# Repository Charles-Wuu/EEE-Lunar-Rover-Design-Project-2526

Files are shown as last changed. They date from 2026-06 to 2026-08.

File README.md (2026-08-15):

# EEE Lunar Rover Project 2026 - Group 25

**Good news! Our work was selected by the Department of EEE for the Best First
Year Project 2026 prize, recognising the dedication and hard work of the whole
team. Congratulations to everyone involved.**

This repository contains the organised software, firmware, CAD, presentation,
and final report materials for the Group 25 ELEC40006 summer rover project.

The rover is a WiFi-controlled lunar surface rover designed to navigate towards
artificial rocks, read their magnetic, infrared, ultrasound, and RF signals, and
classify the rock type from those sensor readings.

Artificial Lunar Surface

## Project photos

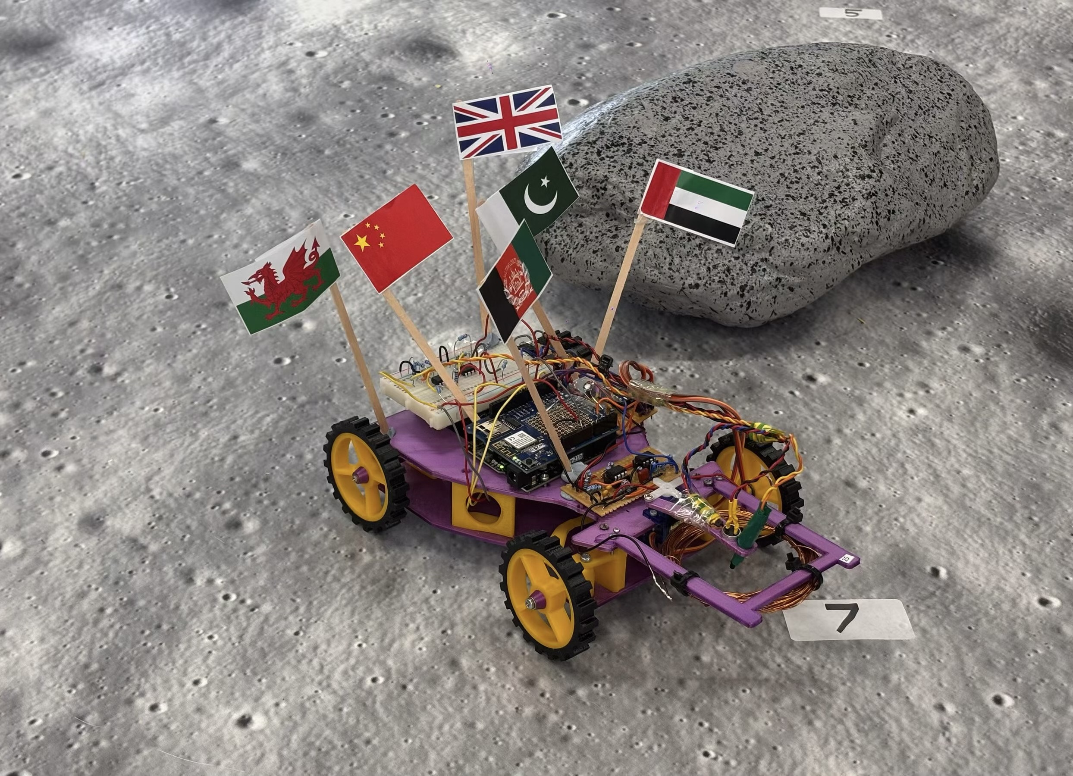
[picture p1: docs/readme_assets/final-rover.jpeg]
Final rover


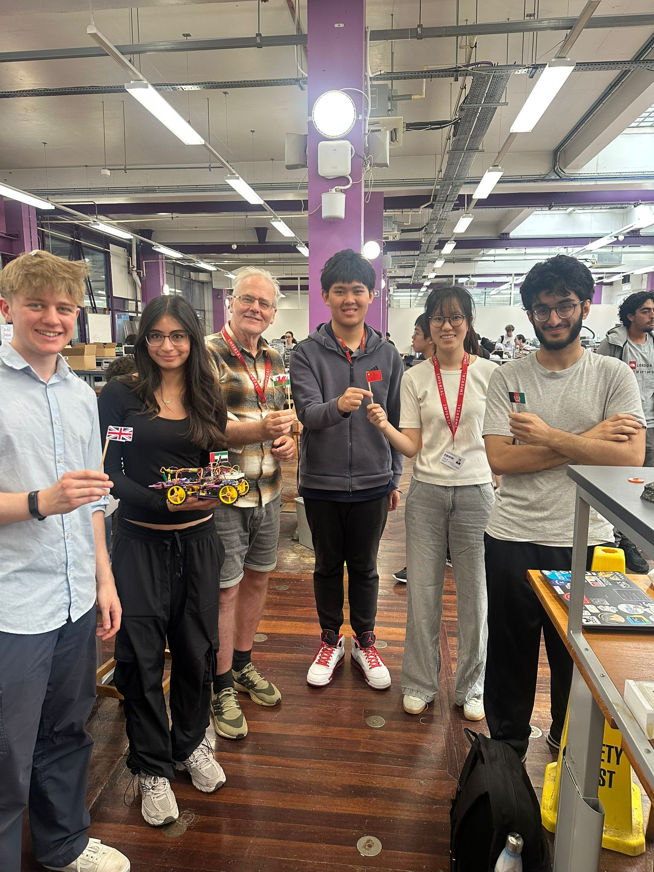
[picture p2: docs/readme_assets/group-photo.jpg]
Group photo


## Repository layout

| Path | Contents |
| --- | --- |
| [`firmware/arduino/final/`](firmware/arduino/final/) | Final combined rover control and detection Arduino sketch. |
| [`firmware/arduino/tests/`](firmware/arduino/tests/) | Earlier tested sketches for control, detection, and RF experiments. |
| [`software/web/`](software/web/) | Flask bridge server and browser interfaces for control and detection. |
| [`mechanical/cad/`](mechanical/cad/) | Full rover STL assembly and individual 3D-printable STL parts. |
| [`docs/report/`](docs/report/) | Final project report PDF. |
| [`docs/presentation/`](docs/presentation/) | Interim presentation PDF. |

## System summary

- Primary controller: Adafruit Metro M0 Express with WINC1500 WiFi shield.
- Rover structure: rear-wheel drive with front-wheel steering.
- Sensor head: combined magnetic, IR, ultrasound, and RF sensing mount.
- Front end: browser pages for mode selection, manual control, and detection.
- Server bridge: Flask app that proxies commands/data between a laptop and the rover.

## Rock classification

| Rock type | IR rate | Ultrasound | Magnetic polarity |
| --- | --- | --- | --- |
| Basaltoid | High, lambda >= 430 | Detected | Down |
| Gravion | Low, lambda < 430 | Absent | Down |
| Regolix | Low, lambda < 430 | Detected | Up |
| Lunarite | High, lambda >= 430 | Absent | Up |

The RF signal provides the rock age as a UART-encoded RF signal using an 89 kHz
carrier frequency.

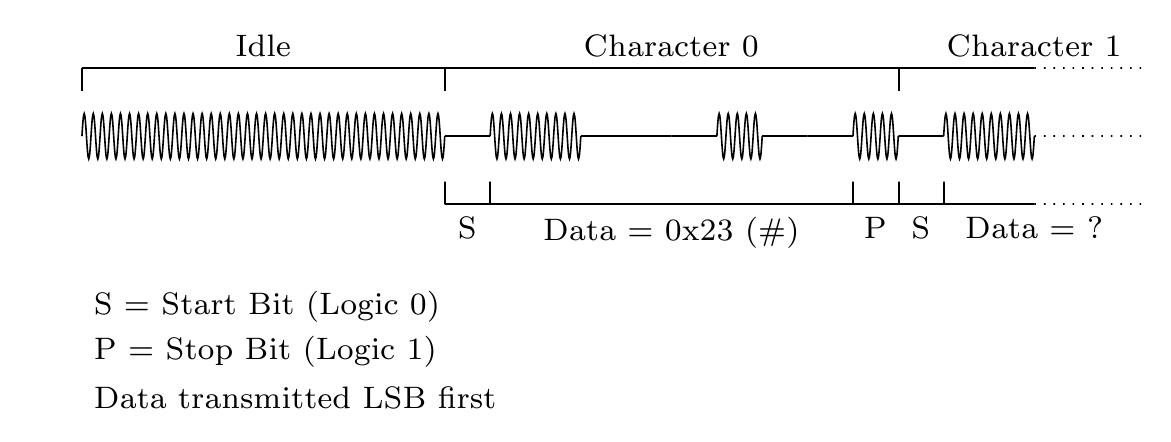
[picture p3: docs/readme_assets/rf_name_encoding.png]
RF signal age encoding


The classification logic is implemented in both the Arduino firmware and the
Flask bridge so that the front end can continue to display a sensible result
when the Arduino omits `rock_type`.

## Quick start

1. Open [`firmware/arduino/final/control_monitor_combined/control_monitor_combined.ino`](firmware/arduino/final/control_monitor_combined/control_monitor_combined.ino).
2. Replace `YOUR_WIFI_SSID` and `YOUR_WIFI_PASSWORD` with the rover WiFi details.
3. Upload the sketch to the Adafruit Metro M0 Express from the Arduino IDE.
4. Run the web bridge:

```bash
cd software/web
python3 -m venv .venv
source .venv/bin/activate
pip install -r requirements.txt
ARDUINO_URL=http://<rover-ip> python rover_server.py
```

5. Open `http://localhost:5050` in a browser.

EL.PSY.KONGROO

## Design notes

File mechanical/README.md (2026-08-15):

# Mechanical and CAD

3D-printable rover geometry exported as STL.

## Structure development

Figure 1 shows the earliest structure used at the start of the project. It was
built entirely from lab kit materials and designs, with no additional parts
required. This version used two motors with differential steering.

Initial lab-kit differential-steering structure

*Figure 1. Initial lab-kit differential-steering structure.*

Figure 2 shows the final rover structure designed by the group. It uses a
unique steering system and is implemented entirely with 3D-printed parts. The
design inspiration and prototype reference came from the open-source PYPER2
project by Tim Hanewich: [TimHanewich/PYPER2](https://github.com/TimHanewich/PYPER2).
It is an incredible piece of work, and we would like to thank Tim Hanewich for
sharing it.

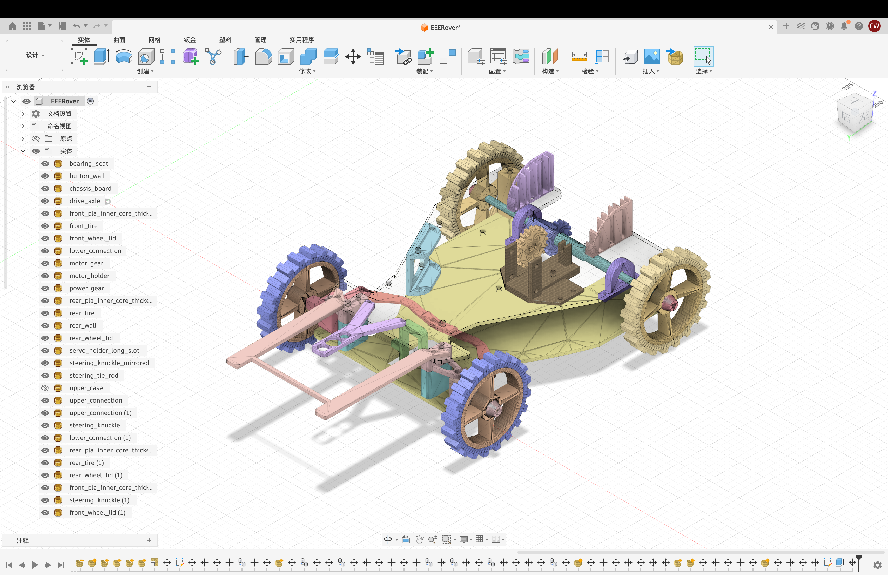
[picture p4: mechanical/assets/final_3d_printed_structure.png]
Final 3D-printed rover structure


*Figure 2. Final 3D-printed rover structure with custom steering.*

## Layout

- `cad/fully_assembled_rover.stl` - full rover assembly.
- `cad/parts/` - individual printable parts for the chassis, transmission,
  steering, sensor mount, board mounts, wheels, and enclosure.

## Design summary

The final rover uses rear-wheel drive and front-wheel steering. A single rear
drive motor powers the back axle through gears, while an SG90 servo controls
the front steering linkage. A second servo moves the sensor mount so the
magnetic, IR, ultrasound, and RF sensors can be aligned with the target rock.

The report records a final rover mass of 512 g, below the 750 g limit.

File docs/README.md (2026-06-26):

# Documentation

Project documentation kept in the repository.

## Layout

- `report/final/` - final submitted PDF report.
- `presentation/` - interim presentation PDF.
- `materials_inventory.md` - source-to-repository organisation record.

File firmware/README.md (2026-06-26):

# Firmware

Arduino sketches for the rover control, detection, and RF receiver work.

## Final sketch

`arduino/final/control_monitor_combined/control_monitor_combined.ino` is the
main delivered sketch. It combines:

- WiFi HTTP endpoints for driving, steering, and probe servo control.
- Magnetic polarity sensing on `A0`.
- IR pulse counting and lambda classification.
- Ultrasound presence detection.
- RF packet and age decoding.
- `/data` JSON output for the web interface.

## Test sketches

`arduino/tests/` keeps earlier working sketches so that individual subsystems
can be tested in isolation:

- `control_final_worked` - drive, steering, and probe servo control.
- `monitor_worked_test` - sensor monitoring and rock classification.
- `eee_rover_inverted_rf_test` - RF receiver testing.
- `radio_freq_code` - earlier RF/control integration kept from the original repository.

## Network setup

The committed sketches use placeholder WiFi credentials:

```cpp
const char ssid[] = "YOUR_WIFI_SSID";
const char pass[] = "YOUR_WIFI_PASSWORD";
```

Set these locally before uploading to the board. Do not commit real network
passwords.

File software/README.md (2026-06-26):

# Software

Laptop-side software and browser interfaces for controlling the rover and
viewing detection data.

The current implementation is in `web/`.

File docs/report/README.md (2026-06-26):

# Report

Final report materials for ELEC40006 Project Report Group 25.

## Final report

`final/elec40006_project_report_group_25.pdf`

The report covers:

- project aims and rover requirements;
- rock PCB and sensing signal characteristics;
- RF, ultrasound, infrared, and magnetic circuit design;
- PCB design;
- software architecture and rock classification;
- mechanical and CAD design;
- conclusion and professional reflection.

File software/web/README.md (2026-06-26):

# Web Interface

This folder contains the Flask bridge server and static browser pages.

## Files

- `rover_server.py` - Flask app that polls the Arduino `/data` endpoint and forwards drive commands.
- `index.html` - landing page for choosing control or detection mode.

  Index page

- `control.html` - keyboard/manual rover control page.

  Control page

- `detect.html` - live rock classification and sensor telemetry page.

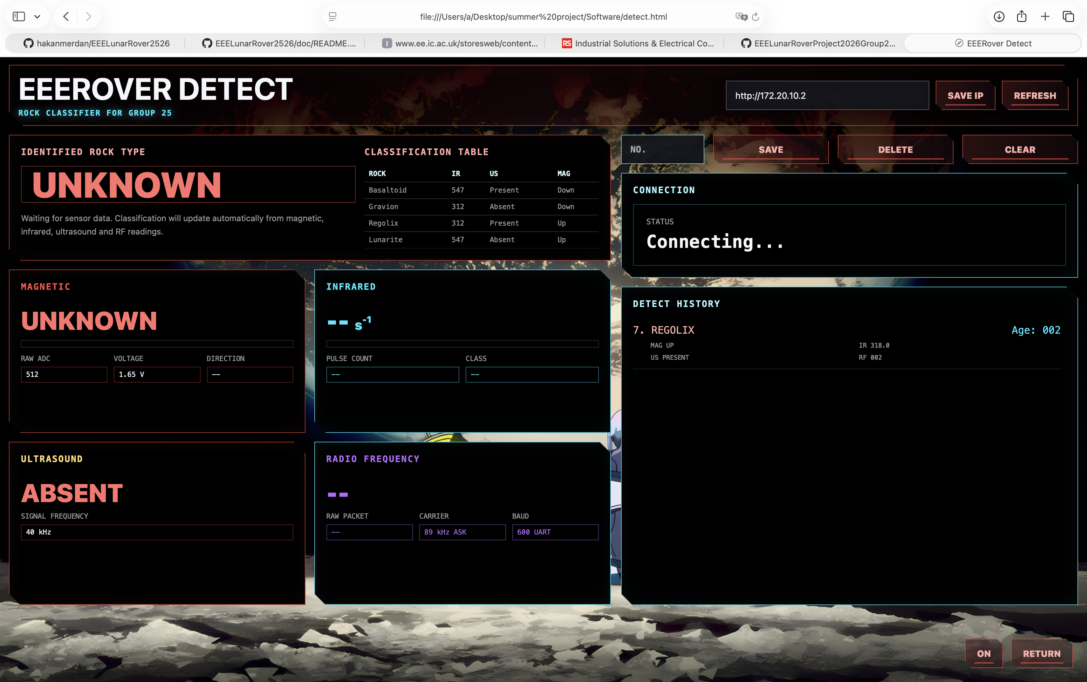
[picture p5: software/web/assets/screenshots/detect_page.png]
Detect page
  

- `assets/` - background images and screenshots used by the web interface.

## Run locally

```bash
python3 -m venv .venv
source .venv/bin/activate
pip install -r requirements.txt
ARDUINO_URL=http://<rover-ip> python rover_server.py
```

Environment variables:

- `ARDUINO_URL` - rover HTTP server address. Default: `http://172.20.10.2`.
- `HOST` - Flask host. Default: `0.0.0.0`.
- `PORT` - Flask port. Default: `5050`.

Open `http://localhost:5050` after the server starts.

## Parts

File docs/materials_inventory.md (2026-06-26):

# Materials Inventory

This file records how the desktop project materials were organised for GitHub.

## Included

- `3D Printing/Fully_Assembled_Rover.stl` -> `mechanical/cad/fully_assembled_rover.stl`
- `3D Printing/assembled_rover_separate_stls/*.stl` -> `mechanical/cad/parts/*.stl`
- `Software/app.py` -> `software/web/rover_server.py`
- `Software/index.html`, `control.html`, `detect.html` -> `software/web/`
- `Software/control_monitor_combined/*.ino` -> `firmware/arduino/final/`
- `Software/control_final_worked/*.ino` -> `firmware/arduino/tests/control_final_worked/`
- `Software/monitor_worked_test/*.ino` -> `firmware/arduino/tests/monitor_worked_test/`
- existing repository RF sketch -> `firmware/arduino/tests/radio_freq_code/`
- `Report Writing/ELEC40006-Project_Report_Group_25.pdf` -> `docs/report/final/`
- `Downloads/Group Project Interim Presentation 2026.pdf` -> `docs/presentation/`

## Excluded

- `.DS_Store` files - macOS metadata.
- `Software/.venv/` - local Python virtual environment.
- all files under `Software/草稿/`.
- all files under `Report Writing/草稿/`.

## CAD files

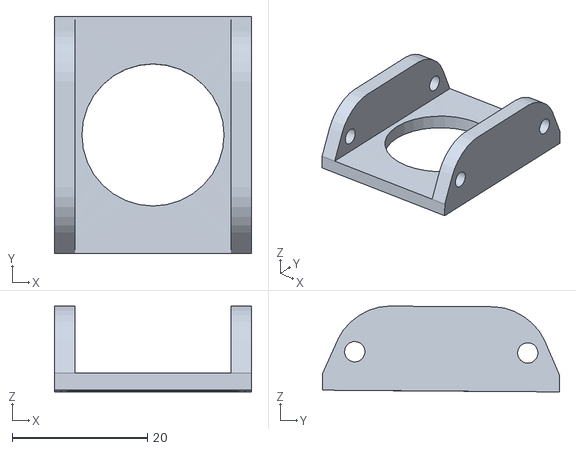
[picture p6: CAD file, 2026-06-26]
mechanical/cad/parts/button_wall.stl
29.1 x 35.0 x 12.7

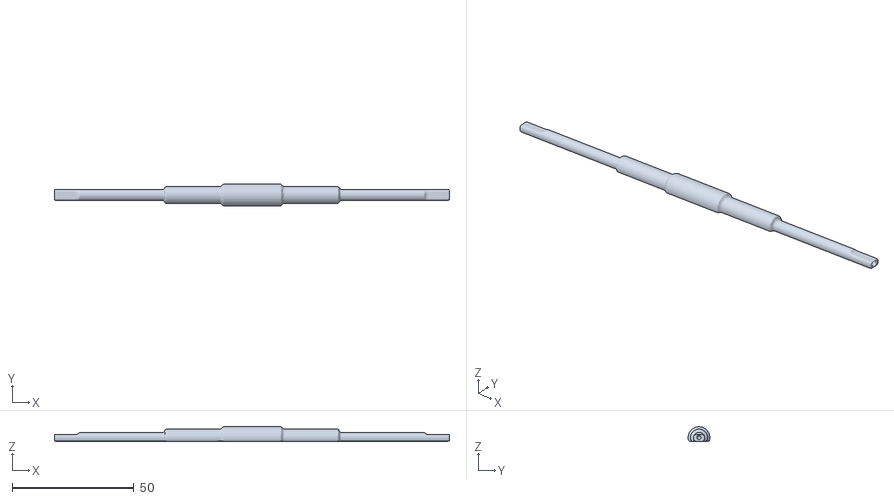
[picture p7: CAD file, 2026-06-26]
mechanical/cad/parts/drive_axle.stl
162.5 x 8.98 x 6.01

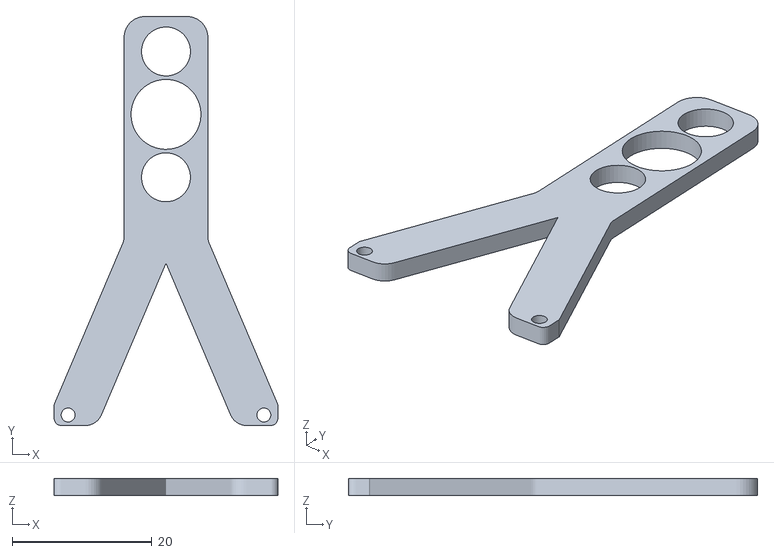
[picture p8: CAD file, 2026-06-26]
mechanical/cad/parts/rotating_mounting.stl
32.0 x 58.5 x 2.50

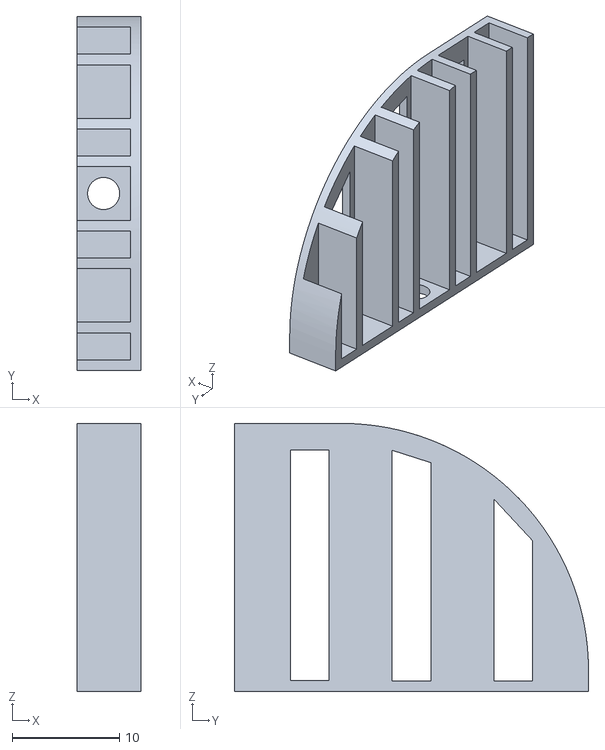
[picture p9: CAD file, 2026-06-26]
mechanical/cad/parts/right_hold.stl
6.00 x 33.0 x 25.0

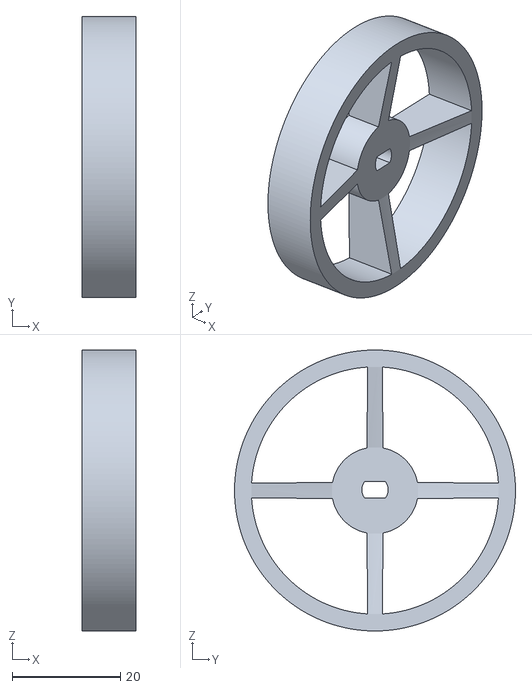
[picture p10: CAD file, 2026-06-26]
mechanical/cad/parts/rear_pla_inner_core_thickened.stl
10.0 x 52.0 x 52.0

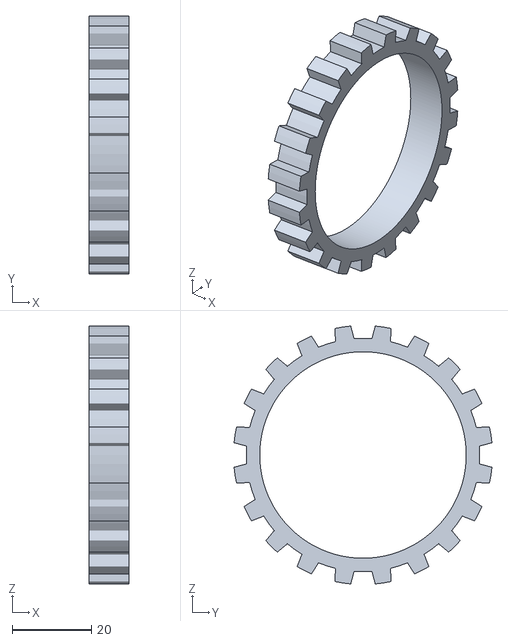
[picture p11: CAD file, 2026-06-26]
mechanical/cad/parts/rear_tire.stl
10.0 x 65.0 x 65.0

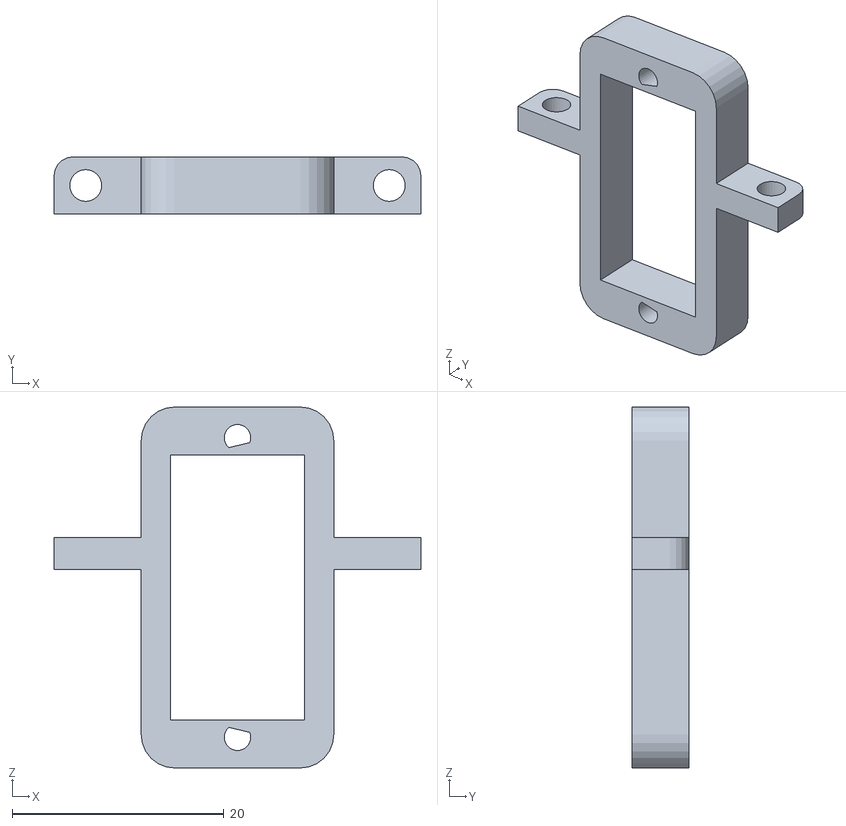
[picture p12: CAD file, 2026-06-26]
mechanical/cad/parts/servo_holder_long_slot.stl
34.7 x 5.43 x 34.1

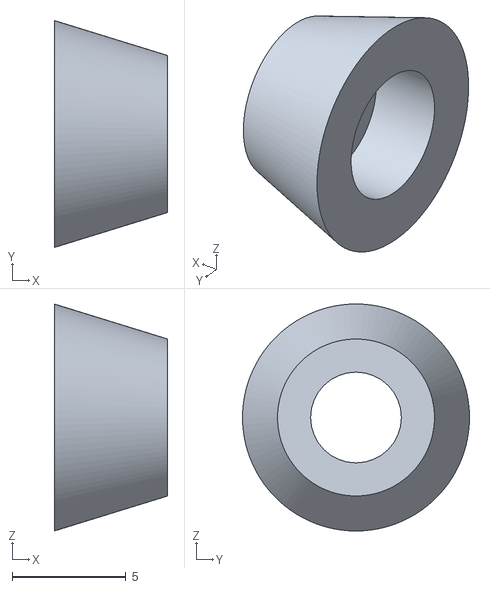
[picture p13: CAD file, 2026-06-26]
mechanical/cad/parts/front_wheel_lid.stl
5.00 x 10.0 x 10.0

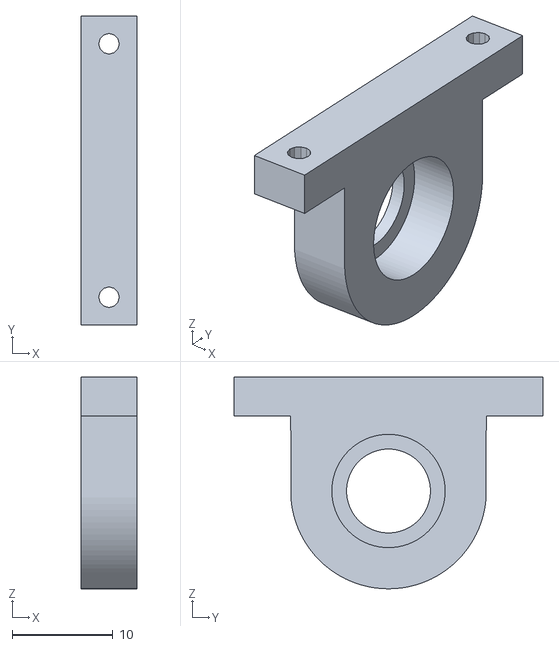
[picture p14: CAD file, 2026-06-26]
mechanical/cad/parts/bearing_seat.stl
5.51 x 30.6 x 21.0

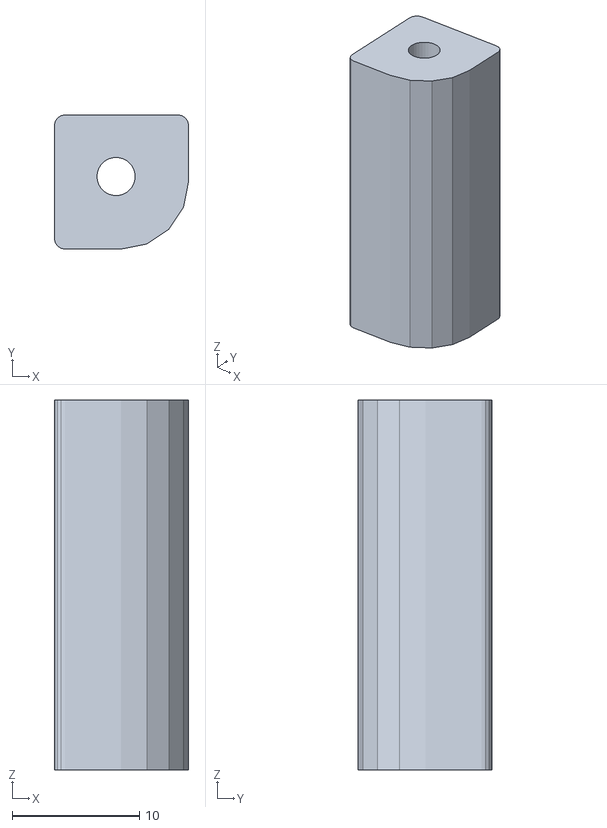
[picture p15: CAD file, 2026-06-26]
mechanical/cad/parts/rear_wall.stl
10.6 x 10.6 x 29.1

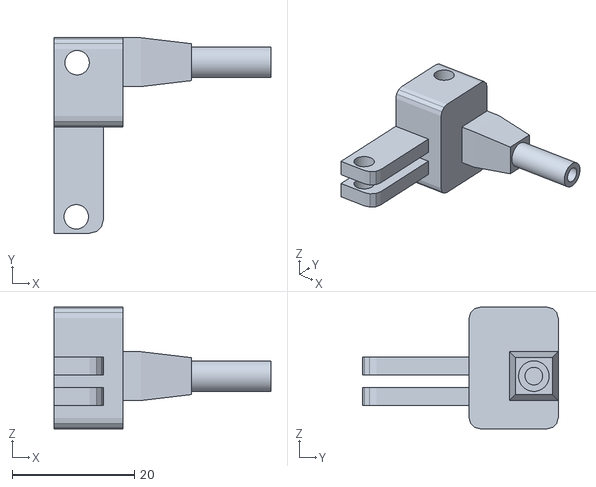
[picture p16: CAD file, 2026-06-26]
mechanical/cad/parts/steering_knuckle_mirrored.stl
35.5 x 32.0 x 19.9

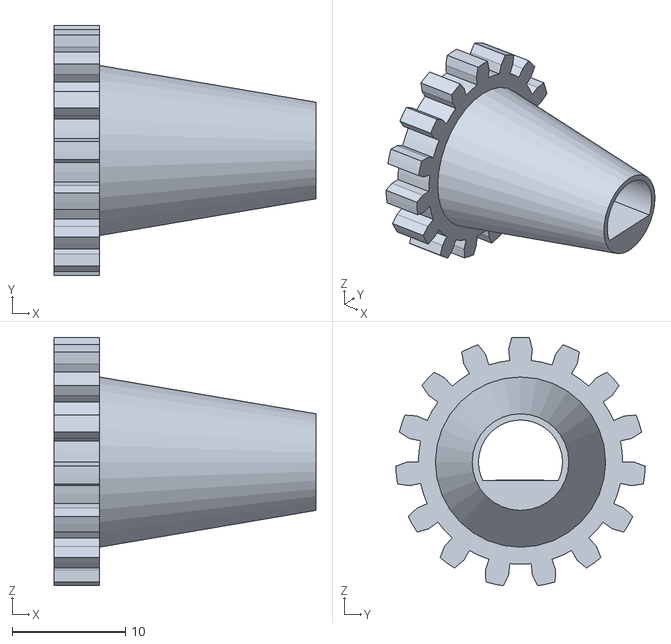
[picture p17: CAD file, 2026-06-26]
mechanical/cad/parts/power_gear.stl
23.1 x 22.0 x 21.9

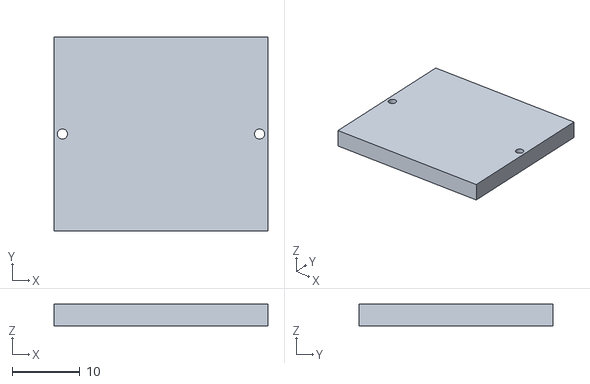
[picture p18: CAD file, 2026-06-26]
mechanical/cad/parts/battery_holder.stl
31.5 x 28.5 x 3.20

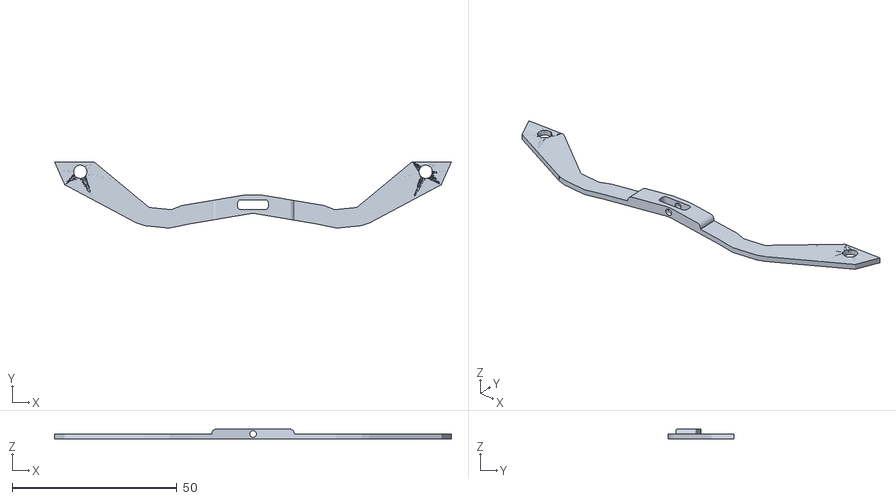
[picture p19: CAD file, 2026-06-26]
mechanical/cad/parts/steering_tie_rod.stl
120.4 x 20.1 x 3.00

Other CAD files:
mechanical/cad/parts/upper_case.stl
mechanical/cad/parts/front_pla_inner_core_thickened.stl
mechanical/cad/parts/rear_wheel_lid.stl
mechanical/cad/parts/sensor_mount_v3.stl
mechanical/cad/parts/chassis_board.stl
mechanical/cad/parts/front_tire.stl
mechanical/cad/parts/left_hold.stl
mechanical/cad/parts/lower_connection.stl
mechanical/cad/parts/metro_m0_plate.stl
mechanical/cad/parts/motor_gear.stl
mechanical/cad/parts/sensor_mount_v1.stl
mechanical/cad/parts/sensor_mount_v2.stl
mechanical/cad/parts/upper_connection.stl

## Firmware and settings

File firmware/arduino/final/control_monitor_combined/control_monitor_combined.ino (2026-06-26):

/**************************************************************************************************************************************
  EEE Rover combined control + detection server

  Combined from:
    - control_final_worked.ino
    - monitor_worked_test.ino

  Web endpoints:
    Control:
      /state
      /forward /backward /stopMotor
      /left /right /center /stop
      /probeDown /probeUp /probeReset
      /on /off

    Detection:
      /data

  Pin plan, avoiding D5, D7 and D10:
    RF input:        D0 / RX, Serial1 @ 600 baud
    Motor EN:        D8
    Motor DIR:       D2
    Steering servo:  D3
    Probe servo:     D4
    Magnetic sensor: A0
    IR sensor:       D9
    Ultrasound:      D6
 ***************************************************************************************************************************************/

#include <Servo.h>

#define USE_WIFI_NINA false
#define USE_WIFI101   true
#include <WiFiWebServer.h>


// ======================================================================
// WiFi
// ======================================================================

const char ssid[] = "YOUR_WIFI_SSID";
const char pass[] = "YOUR_WIFI_PASSWORD";
const int groupNumber = 0;

WiFiWebServer server(80);
bool wifiReady = false;


// ======================================================================
// Pins
// D5, D7 and D10 are intentionally unused.
// ======================================================================

const int MOTOR_EN  = 8;   // moved off D1 to avoid Serial1/TX interaction
const int MOTOR_DIR = 2;
const int SERVO_PIN = 3;
const int PROBE_SERVO_PIN = 4;

#define PIN_MAG_SENSOR A0
#define PIN_IR_SENSOR  9
#define PIN_US_SENSOR  6

// RF output -> D0 / RX
#define RF_BAUD 600


// ======================================================================
// Rover control state
// ======================================================================

Servo steeringServo;
Servo probeServo;

const int LEFT_ANGLE = 45;
const int CENTER_ANGLE = 90;
const int RIGHT_ANGLE = 135;

const int PROBE_MIN_ANGLE = 0;
const int PROBE_CENTER_ANGLE = 90;
const int PROBE_MAX_ANGLE = 180;
const int PROBE_STEP = 10;

int probeAngle = PROBE_CENTER_ANGLE;
String currentMotor = "STOP";
String currentSteering = "CENTER";

// Swap HIGH & LOW if actual movement is reverse to expected.
const int FORWARD_DIR = LOW;
const int BACKWARD_DIR = HIGH;


// ======================================================================
// Detection values and timing
// ======================================================================

#define AREF_VOLTAGE 3.3

#define MAG_UNKNOWN_CENTER_V 2.34
#define MAG_UNKNOWN_HALF_WIDTH_V 0.1
#define V_THRESHOLD_HIGH (MAG_UNKNOWN_CENTER_V + MAG_UNKNOWN_HALF_WIDTH_V)
#define V_THRESHOLD_LOW  (MAG_UNKNOWN_CENTER_V - MAG_UNKNOWN_HALF_WIDTH_V)

int magRaw = 0;
float magVoltage = 0.0;
String magPolarity = "unknown";

volatile unsigned long irPulseCount = 0;
unsigned long irCount = 0;
float irLambda = 0.0;
String irClass = "low";
bool usDetected = false;

unsigned long lastIRTime = 0;
unsigned long lastMagTime = 0;
unsigned long lastUSTime = 0;
unsigned long lastRadioPrintTime = 0;
unsigned long lastHeartbeatTime = 0;
unsigned long lastRFCharTime = 0;

const unsigned long IR_WINDOW_MS = 2000;
const unsigned long MAG_INTERVAL_MS = 500;
const unsigned long US_INTERVAL_MS = 500;
const unsigned long RADIO_PRINT_INTERVAL_MS = 1000;
const unsigned long HEARTBEAT_INTERVAL_MS = 2000;
const unsigned long NO_SIGNAL_TIMEOUT_MS = 2000;

String radioBuffer = "";
String latestRadioPacket = "NO SIGNAL";
String latestRadioAge = "NO SIGNAL";
bool radioReceiving = false;

enum RoverMode
{
  MODE_IDLE,
  MODE_CONTROL,
  MODE_DETECT
};

RoverMode activeMode = MODE_IDLE;
bool detectionHardwareActive = false;


const char* modeNameText()
{
  if (activeMode == MODE_DETECT)
  {
    return "detect";
  }

  if (activeMode == MODE_CONTROL)
  {
    return "control";
  }

  return "idle";
}


void resetRadioParser();
void countIRPulse();


// ======================================================================
// Response helpers
// ======================================================================

void addCorsHeaders()
{
  server.sendHeader(F("Access-Control-Allow-Origin"), F("*"));
  server.sendHeader(F("Access-Control-Allow-Methods"), F("GET, OPTIONS"));
}


void sendText(const __FlashStringHelper* text)
{
  addCorsHeaders();
  server.send(200, F("text/plain"), text);
}


void sendText(const String& text)
{
  addCorsHeaders();
  server.send(200, F("text/plain"), text);
}


// ======================================================================
// Shared endpoints
// ======================================================================

void handleRoot()
{
  sendText(F("EEE Rover combined control + detection server running"));
}


void handleNotFound()
{
  addCorsHeaders();
  server.send(404, F("text/plain"), F("Not Found"));
}


// ======================================================================
// Control state endpoint
// ======================================================================

void handleState()
{
  String json = "{";
  json += "\"motor\":\"";
  json += currentMotor;
  json += "\",";
  json += "\"steering\":\"";
  json += currentSteering;
  json += "\",";
  json += "\"probe_angle\":";
  json += String(probeAngle);
  json += ",";
  json += "\"mode\":\"";
  json += modeNameText();
  json += "\"";
  json += "}";

  addCorsHeaders();
  server.send(200, F("application/json"), json);
}


// ======================================================================
// Motor, steering and probe
// ======================================================================

void motorForward()
{
  digitalWrite(MOTOR_DIR, FORWARD_DIR);
  digitalWrite(MOTOR_EN, HIGH);
  currentMotor = "FORWARD";
}


void motorBackward()
{
  digitalWrite(MOTOR_DIR, BACKWARD_DIR);
  digitalWrite(MOTOR_EN, HIGH);
  currentMotor = "BACKWARD";
}


void stopMotor()
{
  digitalWrite(MOTOR_EN, LOW);
  currentMotor = "STOP";
}


void steeringLeft()
{
  steeringServo.write(LEFT_ANGLE);
  currentSteering = "LEFT";
}


void steeringRight()
{
  steeringServo.write(RIGHT_ANGLE);
  currentSteering = "RIGHT";
}


void steeringCenter()
{
  steeringServo.write(CENTER_ANGLE);
  currentSteering = "CENTER";
}


void stopRover()
{
  stopMotor();
  steeringCenter();
}


void probeDown()
{
  probeAngle = max(PROBE_MIN_ANGLE, probeAngle + PROBE_STEP);
  probeServo.write(probeAngle);
}


void probeUp()
{
  probeAngle = min(PROBE_MAX_ANGLE, probeAngle - PROBE_STEP);
  probeServo.write(probeAngle);
}


void probeReset()
{
  probeAngle = PROBE_CENTER_ANGLE;
  probeServo.write(probeAngle);
}


// ======================================================================
// Mode switching
// ======================================================================

void stopDetectionHardware()
{
  if (!detectionHardwareActive)
  {
    return;
  }

  detachInterrupt(digitalPinToInterrupt(PIN_IR_SENSOR));
  Serial1.end();
  resetRadioParser();
  detectionHardwareActive = false;
}


void startDetectionHardware()
{
  if (detectionHardwareActive)
  {
    return;
  }

  irPulseCount = 0;
  lastIRTime = millis();
  lastRFCharTime = 0;
  latestRadioPacket = "NO SIGNAL";
  latestRadioAge = "NO SIGNAL";
  resetRadioParser();

  Serial1.begin(RF_BAUD);
  attachInterrupt(digitalPinToInterrupt(PIN_IR_SENSOR), countIRPulse, RISING);
  detectionHardwareActive = true;
}


void activateControlMode()
{
  if (activeMode == MODE_CONTROL && !detectionHardwareActive)
  {
    return;
  }

  stopDetectionHardware();

  if (!steeringServo.attached())
  {
    steeringServo.attach(SERVO_PIN);
  }

  if (!probeServo.attached())
  {
    probeServo.attach(PROBE_SERVO_PIN);
  }

  steeringServo.write(CENTER_ANGLE);
  probeServo.write(probeAngle);
  currentSteering = "CENTER";
  activeMode = MODE_CONTROL;

  Serial.println(F("[MODE] control"));
}


void activateDetectMode()
{
  if (activeMode == MODE_DETECT && detectionHardwareActive)
  {
    return;
  }

  stopRover();

  if (steeringServo.attached())
  {
    steeringServo.detach();
  }

  if (probeServo.attached())
  {
    probeServo.detach();
  }

  startDetectionHardware();
  activeMode = MODE_DETECT;

  Serial.println(F("[MODE] detect"));
}


void handleModeControl()
{
  activateControlMode();
  sendText(F("MODE control"));
}


void handleModeDetect()
{
  activateDetectMode();
  sendText(F("MODE detect"));
}


void handleModeStatus()
{
  String json = "{";
  json += "\"mode\":\"";
  json += modeNameText();
  json += "\",";
  json += "\"detection_active\":";
  json += detectionHardwareActive ? "true" : "false";
  json += "}";

  addCorsHeaders();
  server.send(200, F("application/json"), json);
}


bool requireControlMode()
{
  if (activeMode == MODE_CONTROL)
  {
    return true;
  }

  sendText(F("CONTROL MODE OFF"));
  return false;
}


void handleForward()
{
  if (!requireControlMode()) return;
  motorForward();
  sendText(F("FORWARD"));
}


void handleBackward()
{
  if (!requireControlMode()) return;
  motorBackward();
  sendText(F("BACKWARD"));
}


void handleStopMotor()
{
  if (!requireControlMode()) return;
  stopMotor();
  sendText(F("MOTOR STOP"));
}


void handleLeft()
{
  if (!requireControlMode()) return;
  steeringLeft();
  sendText(F("LEFT"));
}


void handleRight()
{
  if (!requireControlMode()) return;
  steeringRight();
  sendText(F("RIGHT"));
}


void handleCenter()
{
  if (!requireControlMode()) return;
  steeringCenter();
  sendText(F("CENTER"));
}


void handleStop()
{
  if (!requireControlMode()) return;
  stopRover();
  sendText(F("STOP"));
}


void handleProbeDown()
{
  if (!requireControlMode()) return;
  probeDown();
  sendText(String("PROBE ") + String(probeAngle));
}


void handleProbeUp()
{
  if (!requireControlMode()) return;
  probeUp();
  sendText(String("PROBE ") + String(probeAngle));
}


void handleProbeReset()
{
  if (!requireControlMode()) return;
  probeReset();
  sendText(F("PROBE 90"));
}


void ledON()
{
  if (!requireControlMode()) return;
  digitalWrite(LED_BUILTIN, HIGH);
  sendText(F("ON"));
}


void ledOFF()
{
  if (!requireControlMode()) return;
  digitalWrite(LED_BUILTIN, LOW);
  sendText(F("OFF"));
}


// ======================================================================
// Detection classification and data endpoint
// ======================================================================

String classifyRock()
{
  bool irHigh = irLambda >= 430.0;

  if (irHigh && usDetected && magPolarity == "down")
  {
    return "Basaltoid";
  }

  if (!irHigh && !usDetected && magPolarity == "down")
  {
    return "Gravion";
  }

  if (!irHigh && usDetected && magPolarity == "up")
  {
    return "Regolix";
  }

  if (irHigh && !usDetected && magPolarity == "up")
  {
    return "Lunarite";
  }

  return "unknown";
}


void handleData()
{
  String json = "{";

  json += "\"mag\":{";
  json += "\"raw\":" + String(magRaw) + ",";
  json += "\"voltage\":" + String(magVoltage, 2) + ",";
  json += "\"polarity\":\"" + magPolarity + "\"";
  json += "},";

  json += "\"ir\":{";
  json += "\"count\":" + String(irCount) + ",";
  json += "\"lambda_val\":" + String(irLambda, 1) + ",";
  json += "\"ir_class\":\"" + irClass + "\"";
  json += "},";

  json += "\"us\":{";
  json += "\"detected\":";
  json += usDetected ? "true" : "false";
  json += "},";

  bool rfNoSignal = lastRFCharTime == 0 || millis() - lastRFCharTime > NO_SIGNAL_TIMEOUT_MS;

  json += "\"rf\":{";
  json += "\"packet\":\"";
  json += rfNoSignal ? "NO SIGNAL" : latestRadioPacket;
  json += "\",";
  json += "\"age\":\"";
  json += rfNoSignal ? "NO SIGNAL" : latestRadioAge;
  json += "\",";
  json += "\"status\":\"";
  json += rfNoSignal ? "no_signal" : "live";
  json += "\"";
  json += "},";

  json += "\"rock_type\":\"" + classifyRock() + "\"";
  json += "}";

  addCorsHeaders();
  server.send(200, F("application/json"), json);
}


// ======================================================================
// Detection: magnetic
// ======================================================================

int readMagSmoothed()
{
  long sum = 0;

  for (int i = 0; i < 16; i++)
  {
    sum += analogRead(PIN_MAG_SENSOR);
    delay(2);
  }

  return sum / 16;
}


void updateMagnetic()
{
  unsigned long now = millis();

  if (now - lastMagTime < MAG_INTERVAL_MS)
  {
    return;
  }

  lastMagTime = now;

  magRaw = readMagSmoothed();
  magVoltage = (magRaw / 1023.0) * AREF_VOLTAGE;

  if (magVoltage > V_THRESHOLD_HIGH)
  {
    magPolarity = "up";
  }
  else if (magVoltage < V_THRESHOLD_LOW)
  {
    magPolarity = "down";
  }
  else
  {
    magPolarity = "unknown";
  }
}


// ======================================================================
// Detection: IR pulse count
// ======================================================================

void countIRPulse()
{
  irPulseCount++;
}


void updateIR()
{
  unsigned long now = millis();

  if (now - lastIRTime < IR_WINDOW_MS)
  {
    return;
  }

  lastIRTime = now;

  noInterrupts();
  unsigned long count = irPulseCount;
  irPulseCount = 0;
  interrupts();

  irCount = count;
  irLambda = count / 2.0;

  if (irLambda >= 430.0)
  {
    irClass = "high";
  }
  else
  {
    irClass = "low";
  }

  Serial.print(F("[IR] count="));
  Serial.print(irCount);
  Serial.print(F(" lambda="));
  Serial.print(irLambda, 1);
  Serial.print(F(" s^-1 class="));
  Serial.println(irClass);
}


// ======================================================================
// Detection: ultrasound
// ======================================================================

void updateUltrasound()
{
  unsigned long now = millis();

  if (now - lastUSTime < US_INTERVAL_MS)
  {
    return;
  }

  lastUSTime = now;
  usDetected = digitalRead(PIN_US_SENSOR) == HIGH;
}


// ======================================================================
// Detection: RF UART
// This keeps the tested #DDD packet rule.
// ======================================================================

void resetRadioParser()
{
  radioBuffer = "";
  radioReceiving = false;
}


void publishRadioPacket()
{
  String digits = radioBuffer.substring(1);

  latestRadioPacket = digits;
  latestRadioAge = digits;

  Serial.print(F("[RF packet] "));
  Serial.println(latestRadioPacket);
}


void processRadioChar(char c)
{
  lastRFCharTime = millis();

  if (!radioReceiving)
  {
    if (c == '#')
    {
      radioBuffer = "#";
      radioReceiving = true;
    }

    return;
  }

  if (c >= '0' && c <= '9')
  {
    radioBuffer += c;

    if (radioBuffer.length() == 4)
    {
      publishRadioPacket();
      resetRadioParser();
    }

    return;
  }

  if (c == '#')
  {
    radioBuffer = "#";
    radioReceiving = true;
  }
  else
  {
    resetRadioParser();
  }
}


void updateRadio()
{
  while (Serial1.available() > 0)
  {
    char c = (char)Serial1.read();
    processRadioChar(c);
  }
}


void printRFStatus()
{
  unsigned long now = millis();

  if (now - lastRadioPrintTime < RADIO_PRINT_INTERVAL_MS)
  {
    return;
  }

  lastRadioPrintTime = now;

  if (lastRFCharTime == 0 || now - lastRFCharTime > NO_SIGNAL_TIMEOUT_MS)
  {
    Serial.println(F("[RF] no signal"));
  }
  else
  {
    Serial.print(F("[Latest RF packet] "));
    Serial.println(latestRadioPacket);
  }
}


// ======================================================================
// Serial commands
// ======================================================================

void handleSerialCommand(char cmd)
{
  if (cmd == 'w' || cmd == 'W')
  {
    motorForward();
    Serial.println(F("Motor forward"));
  }
  else if (cmd == 's' || cmd == 'S')
  {
    motorBackward();
    Serial.println(F("Motor backward"));
  }
  else if (cmd == 'a' || cmd == 'A')
  {
    steeringLeft();
    Serial.println(F("Servo left 45"));
  }
  else if (cmd == 'd' || cmd == 'D')
  {
    steeringRight();
    Serial.println(F("Servo right 135"));
  }
  else if (cmd == 'q' || cmd == 'Q')
  {
    probeDown();
    Serial.print(F("Probe servo "));
    Serial.println(probeAngle);
  }
  else if (cmd == 'e' || cmd == 'E')
  {
    probeUp();
    Serial.print(F("Probe servo "));
    Serial.println(probeAngle);
  }
  else if (cmd == 'r' || cmd == 'R')
  {
    probeReset();
    Serial.println(F("Probe servo reset 90"));
  }
  else if (cmd == 'x' || cmd == 'X')
  {
    stopRover();
    Serial.println(F("Stop motor, servo center"));
  }
}


// ======================================================================
// Setup helpers
// ======================================================================

void registerRoutes()
{
  server.on(F("/"), handleRoot);

  server.on(F("/state"), handleState);
  server.on(F("/data"), handleData);

  server.on(F("/mode/control"), handleModeControl);
  server.on(F("/mode/detect"), handleModeDetect);
  server.on(F("/mode/status"), handleModeStatus);

  server.on(F("/on"), ledON);
  server.on(F("/off"), ledOFF);

  server.on(F("/forward"), handleForward);
  server.on(F("/backward"), handleBackward);
  server.on(F("/stopMotor"), handleStopMotor);
  server.on(F("/left"), handleLeft);
  server.on(F("/right"), handleRight);
  server.on(F("/center"), handleCenter);
  server.on(F("/stop"), handleStop);

  server.on(F("/probeDown"), handleProbeDown);
  server.on(F("/probeUp"), handleProbeUp);
  server.on(F("/probeReset"), handleProbeReset);

  server.onNotFound(handleNotFound);
}


void connectWiFi()
{
  if (WiFi.status() == WL_NO_SHIELD)
  {
    Serial.println(F("WiFi shield not present"));
    Serial.println(F("Serial control and sensor logging still work."));
    return;
  }

  if (groupNumber)
  {
    WiFi.config(IPAddress(192, 168, 0, groupNumber + 1));
  }

  Serial.print(F("Connecting to WPA SSID: "));
  Serial.println(ssid);

  unsigned long wifiStartTime = millis();

  while (WiFi.begin(ssid, pass) != WL_CONNECTED && millis() - wifiStartTime < 30000)
  {
    delay(500);
    Serial.print('.');
  }

  if (WiFi.status() != WL_CONNECTED)
  {
    Serial.println();
    Serial.println(F("WiFi connection timed out."));
    Serial.println(F("Serial control and sensor logging still work."));
    return;
  }

  registerRoutes();
  server.begin();
  wifiReady = true;

  Serial.print(F("HTTP server started @ "));
  Serial.println(static_cast<IPAddress>(WiFi.localIP()));
}


// ======================================================================
// Setup
// ======================================================================

void setup()
{
  Serial.begin(9600);
  delay(1500);

  Serial.println();
  Serial.println(F("========================================"));
  Serial.println(F("EEE Rover combined control + detection booting"));
  Serial.println(F("Pins D5, D7 and D10 are unused."));
  Serial.println(F("RF input: D0 / RX, Serial1 @ 600 baud"));
  Serial.println(F("========================================"));

  pinMode(LED_BUILTIN, OUTPUT);
  digitalWrite(LED_BUILTIN, LOW);

  pinMode(MOTOR_EN, OUTPUT);
  pinMode(MOTOR_DIR, OUTPUT);
  stopMotor();

  steeringServo.attach(SERVO_PIN);
  steeringCenter();

  probeServo.attach(PROBE_SERVO_PIN);
  probeReset();
  steeringServo.detach();
  probeServo.detach();

  pinMode(PIN_IR_SENSOR, INPUT);
  pinMode(PIN_US_SENSOR, INPUT);

  analogReadResolution(10);

  connectWiFi();
}


// ======================================================================
// Loop
// ======================================================================

void loop()
{
  if (wifiReady)
  {
    server.handleClient();
  }

  while (activeMode == MODE_CONTROL && Serial.available() > 0)
  {
    handleSerialCommand((char)Serial.read());
  }

  if (activeMode == MODE_DETECT)
  {
    updateMagnetic();
    updateIR();
    updateUltrasound();
    updateRadio();
    printRFStatus();
  }

  unsigned long now = millis();

  if (now - lastHeartbeatTime >= HEARTBEAT_INTERVAL_MS)
  {
    lastHeartbeatTime = now;

    Serial.print(F("[HEARTBEAT] wifi="));
    Serial.print(wifiReady ? F("on") : F("off"));

    Serial.print(F(" motor="));
    Serial.print(currentMotor);

    Serial.print(F(" steering="));
    Serial.print(currentSteering);

    Serial.print(F(" probe="));
    Serial.print(probeAngle);

    Serial.print(F(" mag="));
    Serial.print(magPolarity);

    Serial.print(F(" ir="));
    Serial.print(irClass);

    Serial.print(F(" us="));
    Serial.print(usDetected ? F("detected") : F("absent"));

    Serial.print(F(" rf="));
    if (lastRFCharTime == 0 || now - lastRFCharTime > NO_SIGNAL_TIMEOUT_MS)
    {
      Serial.print(F("no signal"));
    }
    else
    {
      Serial.print(latestRadioPacket);
    }

    Serial.print(F(" rock="));
    Serial.println(classifyRock());
  }
}

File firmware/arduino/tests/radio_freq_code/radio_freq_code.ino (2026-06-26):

// ============================================================
// EEERover Control Endpoints + Detection Serial Output
// RF version: standard UART, where HIGH = 1 and LOW = 0.
// ============================================================

#define USE_WIFI_NINA false
#define USE_WIFI101   true
#include <WiFiWebServer.h>


// ======================================================================
// WiFi
// ======================================================================

const char ssid[] = "YOUR_WIFI_SSID";
const char pass[] = "YOUR_WIFI_PASSWORD";
const int groupNumber = 0;

WiFiWebServer server(80);


// ======================================================================
// Motor pins
// ======================================================================

const int leften   = 0;
const int leftdir  = 1;
const int righten  = 2;
const int rightdir = 3;

const int FORWARD  = HIGH;
const int BACKWARD = LOW;

String currentMotor = "STOP";


// ======================================================================
// Detection pins
// ======================================================================

#define PIN_MAG_SENSOR A0
#define PIN_IR_SENSOR  4
#define PIN_US_SENSOR  8

// RF UART input on D6 — standard UART, 600 baud.
// Idle = HIGH, start bit = LOW, data: HIGH=1 LOW=0, LSB first.
#define PIN_RADIO_RX   6
#define RADIO_BAUD     600
#define RADIO_BIT_US   (1000000UL / RADIO_BAUD)   // 1667 µs per bit

#define AREF_VOLTAGE     3.3
#define V_THRESHOLD_HIGH 2.5
#define V_THRESHOLD_LOW  0.9


// ======================================================================
// Detection values and timing
// ======================================================================

int magRaw = 0;
float magVoltage = 0.0;
String magPolarity = "unknown";

volatile unsigned long irPulseCount = 0;
unsigned long irCount = 0;
float irLambda = 0.0;
String irClass = "low";
bool usDetected = false;

unsigned long lastIRTime        = 0;
unsigned long lastMagTime       = 0;
unsigned long lastUSTime        = 0;
unsigned long lastRadioPrintTime = 0;

const unsigned long IR_WINDOW_MS          = 2000;
const unsigned long MAG_INTERVAL_MS       = 500;
const unsigned long US_INTERVAL_MS        = 500;
const unsigned long RADIO_PRINT_INTERVAL_MS = 500;

String latestRadioPacket = "--";
String latestRadioAge    = "--";
String radioBuffer       = "";

// Edge-detection state for the RF pin (must outlive updateRadio calls)
bool rfPrevHigh = true;

bool wifiReady = false;
unsigned long lastHeartbeatTime = 0;
const unsigned long HEARTBEAT_INTERVAL_MS = 2000;


// ======================================================================
// Helper: send response with CORS
// ======================================================================

void sendText(const String& text)
{
  server.sendHeader(F("Access-Control-Allow-Origin"), F("*"));
  server.send(200, F("text/plain"), text);
}


// ======================================================================
// Root
// ======================================================================

void handleRoot()
{
  server.sendHeader(F("Access-Control-Allow-Origin"), F("*"));
  server.send(200, F("text/plain"), F("EEE Rover Arduino is running"));
}


// ======================================================================
// Rock classification
// ======================================================================

String classifyRock()
{
  bool irHigh = irLambda >= 430.0;

  if ( irHigh &&  usDetected && magPolarity == "down") return "Basaltoid";
  if (!irHigh && !usDetected && magPolarity == "down") return "Gravion";
  if (!irHigh &&  usDetected && magPolarity == "up")   return "Regolix";
  if ( irHigh && !usDetected && magPolarity == "up")   return "Lunarite";
  return "unknown";
}


// ======================================================================
// /data endpoint
// ======================================================================

void handleData()
{
  String json = "{";

  json += "\"mag\":{";
  json += "\"raw\":"      + String(magRaw)         + ",";
  json += "\"voltage\":"  + String(magVoltage, 2)  + ",";
  json += "\"polarity\":\"" + magPolarity           + "\"";
  json += "},";

  json += "\"ir\":{";
  json += "\"count\":"      + String(irCount)      + ",";
  json += "\"lambda_val\":" + String(irLambda, 1)  + ",";
  json += "\"ir_class\":\"" + irClass               + "\"";
  json += "},";

  json += "\"us\":{";
  json += "\"detected\":";
  json += usDetected ? "true" : "false";
  json += "},";

  json += "\"rf\":{";
  json += "\"packet\":\"" + latestRadioPacket + "\",";
  json += "\"age\":\""    + latestRadioAge    + "\"";
  json += "},";

  json += "\"rock_type\":\"" + classifyRock() + "\"";
  json += "}";

  server.sendHeader(F("Access-Control-Allow-Origin"), F("*"));
  server.send(200, F("application/json"), json);
}


// ======================================================================
// Motor functions
// ======================================================================

void stopMotors()
{
  digitalWrite(leften,  LOW);
  digitalWrite(righten, LOW);
}

void forward()
{
  digitalWrite(leftdir,  FORWARD);
  digitalWrite(rightdir, FORWARD);
  digitalWrite(leften,   HIGH);
  digitalWrite(righten,  HIGH);
  currentMotor = "FORWARD";
  sendText("FORWARD");
}

void backward()
{
  digitalWrite(leftdir,  BACKWARD);
  digitalWrite(rightdir, BACKWARD);
  digitalWrite(leften,   HIGH);
  digitalWrite(righten,  HIGH);
  currentMotor = "BACKWARD";
  sendText("BACKWARD");
}

void left()
{
  digitalWrite(rightdir, FORWARD);
  digitalWrite(leften,   LOW);
  digitalWrite(righten,  HIGH);
  currentMotor = "LEFT";
  sendText("LEFT");
}

void right()
{
  digitalWrite(leftdir, FORWARD);
  digitalWrite(leften,  HIGH);
  digitalWrite(righten, LOW);
  currentMotor = "RIGHT";
  sendText("RIGHT");
}

void spinLeft()
{
  digitalWrite(leftdir,  BACKWARD);
  digitalWrite(rightdir, FORWARD);
  digitalWrite(leften,   HIGH);
  digitalWrite(righten,  HIGH);
  currentMotor = "SPIN LEFT";
  sendText("SPIN LEFT");
}

void spinRight()
{
  digitalWrite(leftdir,  FORWARD);
  digitalWrite(rightdir, BACKWARD);
  digitalWrite(leften,   HIGH);
  digitalWrite(righten,  HIGH);
  currentMotor = "SPIN RIGHT";
  sendText("SPIN RIGHT");
}

void stopRover()
{
  stopMotors();
  currentMotor = "STOP";
  sendText("STOP");
}

void ledON()
{
  digitalWrite(LED_BUILTIN, HIGH);
  sendText("ON");
}

void ledOFF()
{
  digitalWrite(LED_BUILTIN, LOW);
  sendText("OFF");
}


// ======================================================================
// Detection: Magnetic
// ======================================================================

int readMagSmoothed()
{
  long sum = 0;
  for (int i = 0; i < 16; i++)
  {
    sum += analogRead(PIN_MAG_SENSOR);
    delay(2);
  }
  return sum / 16;
}
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
